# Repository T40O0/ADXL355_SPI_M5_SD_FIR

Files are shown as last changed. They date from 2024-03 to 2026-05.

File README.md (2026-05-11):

# MEMS Seismometer  


## Prerequisite
 - ADXL355 ([EVAL-ADXL355-PMDZ](https://www.analog.com/en/products/adxl355.html#product-overview))
 - [M5Stack Tough](https://docs.m5stack.com/en/core/tough)
 - [modified version](https://github.com/T40O0/M5_ADXL355/tree/M5) of [plasmapper/adxl355-arduino](https://github.com/plasmapper/adxl355-arduino)  
Hats off to PL.

## Features
 - Cost-effective: It can be made for about €100.
 - Records three acceleration components (cm/sec/sec).
 - Selectable output rate at compile time: **100 Hz** or  **500 Hz** .
 - Dual-core FreeRTOS pipeline (TaskRead on PRO_CPU, TaskSave on APP_CPU) decouples sampling from SD I/O.
 - One CSV file per minute on a TF card; daily folder layout (`/YYYYMMDD/HHMM.csv`).
 - Built-in Wi-Fi AP + FTP server for data retrieva.
 - Dust- and water-resistant (do not submerge the case in water or other liquids).
 - Made of UV-resistant plastic, so it can be used outdoors and in areas where acid gases are generated, such as volcanic regions.

## Installation
1. Connect ADXL355  
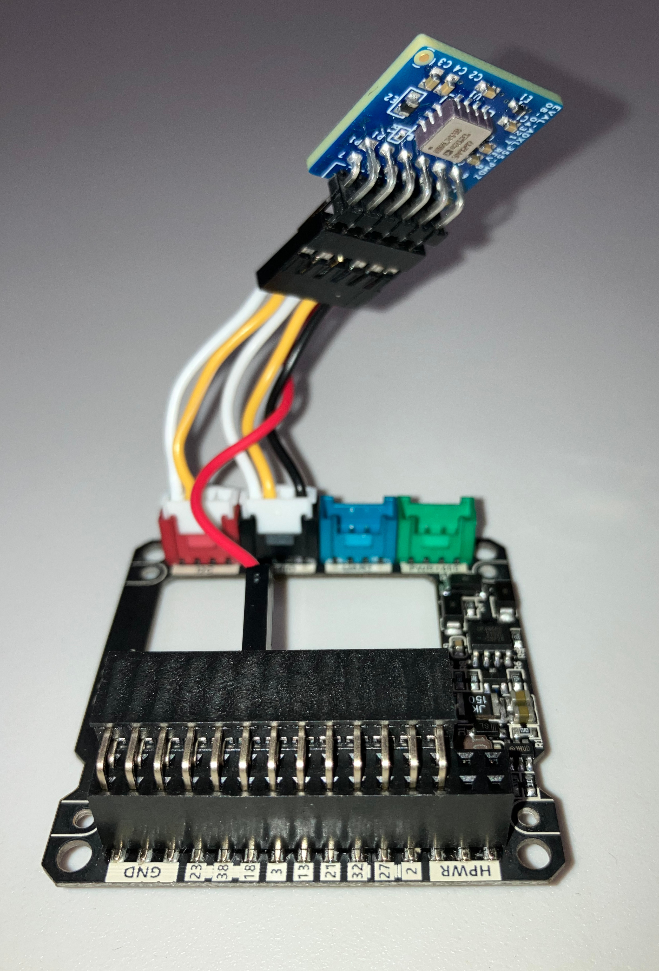
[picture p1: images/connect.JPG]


2. Set  
Mounting the ADXL355 into a [3D-printed frame](3D_model/frame.stl).  
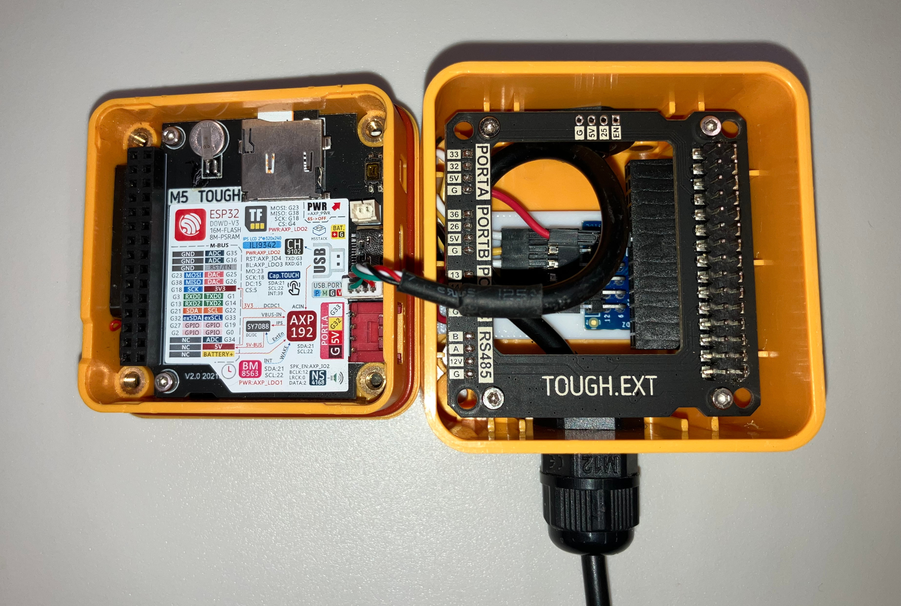
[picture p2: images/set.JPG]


3. Write  
The code can be uploaded to your board using the Arduino IDE.  
FIR coefficient files are bundled in the [`FIR/`](FIR/) subfolder of this sketch and included automatically.

## Sampling rate selection
At the top of the sketch, set the desired output rate:
```cpp
#define SAMPLE_HZ 100  // 100 or 500
```
- `100`: ADXL355 ODR=500 Hz, 201-tap FIR (`FIR/FIR500_cut50.csv`).
- `500`: ADXL355 ODR=1000 Hz, 80-tap minimum-phase FIR (`FIR/min500.cf`).

## How to start
On power-on, a startup screen with four options is shown for 30 seconds. Tap a button, or wait for the timer to elapse.

1. **Wi-Fi Setting** - SmartConfig (set or change the Wi-Fi access point), then NTP sync of the RTC.
2. **Reset RTC** - Connect to a saved Wi-Fi access point and resync the RTC via NTP.
3. **Manual Set** - Set RTC year/month/day/hour/minute/second on the touch screen (no Wi-Fi needed).
4. **Data Dump** - Start a SoftAP + FTP server. Connect a PC to the AP and pull files via Explorer.

After any of the above (or after the 30 second timeout), measurement begins at the next RTC second `00`.

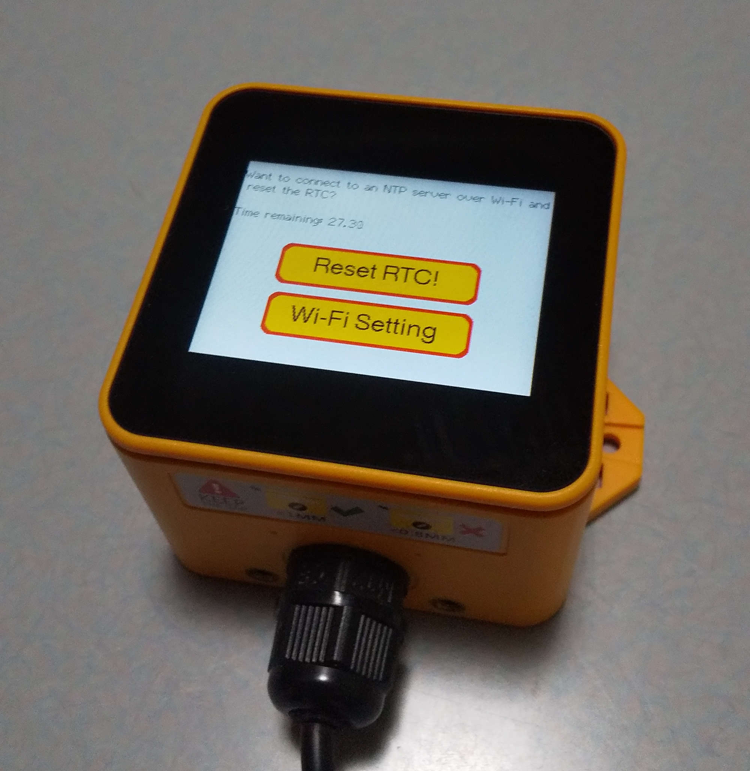
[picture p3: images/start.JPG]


## Note
 - **RTC year range**: measurements only start when the RTC year is in 2026..2099. Edit `setup()` if needed.  
   `while ((dt.date.year < 2026) || (dt.date.year > 2099)) {`
 - **NTP setup**: edit the defines near the top of the sketch to fit your environment.  
   `#define NTP_TIMEZONE  "your zone"`  
   `#define NTP_SERVER1   "your server1"`  
   `#define NTP_SERVER2   "your server2"`  
   `#define NTP_SERVER3   "your server3"`
 - **Wi-Fi setup (first time / new access point)**: choose **Wi-Fi Setting** on the startup screen, then use the *SmartConfig ESP* or *ESP Touch* app on your phone to push the SSID/password. The RTC reset proceeds automatically once the device is connected.
 - **Manual RTC**: use **Manual Set** when no Wi-Fi is available (e.g., remote field deployment). A 10-second confirmation screen is shown before measurement begins.
 - **Data Dump (FTP)**: choose **Data Dump** on the startup screen. The device acts as a SoftAP (`SSID: M5-SEISMO / PASS: m5seismo`). Connect a PC to the AP, then use a dedicated FTP client (**WinSCP**, **FileZilla**, or a web browser) at `ftp://m5:m5@192.168.4.1` to copy files. Tap the on-screen **Reset** button to return to the startup screen.
   - **Avoid Windows Explorer for the FTP transfer.** Explorer's built-in FTP shares the Internet Explorer cache and tends to keep stale copies of files across sessions, so freshly written data may not appear in the downloaded CSV even though the SD card itself is up to date. WinSCP / FileZilla / browsers fetch the current file every time and do not have this issue.
 - **FIR cutoff (100 Hz mode)**: the supplied 201-tap FIR cuts at 50 Hz for a 500 Hz input. Replace `FIR/FIR500_cut50.csv` to change the cutoff.
 - **FIR coefficients (500 Hz mode)**: this sketch ships with `FIR/min500.cf`, an 80-tap minimum-phase FIR (200 Hz passband / 250 Hz stopband at -120 dB) generated by [Telemetra-1](https://telemetra.jp/). Replace `FIR/min500.cf` with your own minimum-phase 80-tap design (declared as `double min500[80] = {...};`) to change the response.
 - **Serial debug output**: per-sample `Time(msec), x, y, z` is emitted on Serial when `#define ENABLE_SERIAL_SAMPLES 1` at the top of the sketch. Default is `0` (disabled). At 500 Hz the four `Serial.print` calls per 1 ms loop saturate the UART and add jitter to the sampling cycle, so keep it `0` for normal recording — enable only for low-rate verification.
 - **File layout**: daily folders `/YYYYMMDD/` contain per-minute files `HHMM.csv`. Each file holds 60 seconds of data, aligned to the RTC second `00`. Data captured between power-on and the first sec=0 boundary is intentionally discarded so file timing matches the file name.
 - **Timestamp resolution**: the `Time(msec)` column is stamped with `millis()` at FIFO-drain time, which has 1 ms resolution. At 500 Hz (true Δt = 2 ms) this means consecutive samples often share the same millisecond (Δt = 0) or fall on adjacent millisecond ticks (Δt = 1–6 ms), producing visible local jitter even though the **total time span** (`last − first ≈ 60000 ms`) per file remains correct. Use this metric — not the per-sample Δt — to verify recording integrity. The **per-file row count** is nominally `hz × 60` but can fluctuate by ±one batch (`hz × SDWriteTime` rows, i.e. ±7500 at 500 Hz / ±1500 at 100 Hz) at minute boundaries: TaskRead is paced by the ESP32 system tick while file rollover follows the M5 RTC (PCF8563), and the two crystals drift independently. When cumulative drift crosses one batch period, two adjacent files temporarily show one extra and one short batch; row timestamps within each file stay accurate.
 - A "[hat](3D_model/hat.stl)" is recommended for outdoor use.
   - [x] Blocks sunlight and protects the LCD.
   - [x] Falling volcanic ash is washed away by rain.
 - Do not submerge the case in water or other liquids.

## Licence
This project bundles components from multiple sources, each under its own licence:
 - **ADXL355 driver code**: based on [plasmapper/adxl355-arduino](https://github.com/plasmapper/adxl355-arduino) (PL) - see the upstream repository for its licence terms.
 - **`FIR/min500.cf` (500 Hz minimum-phase FIR)**: provided by [Telemetra-1](https://telemetra.jp/) - subject to Telemetra's own licence terms.
 - **All other original work in this repository** (sketch code, FIR/FIR500_cut50.csv, 3D models, etc.): MIT licence - see the [LICENSE file](LICENSE) for details.

When redistributing or modifying this project, please honour each component's respective licence.

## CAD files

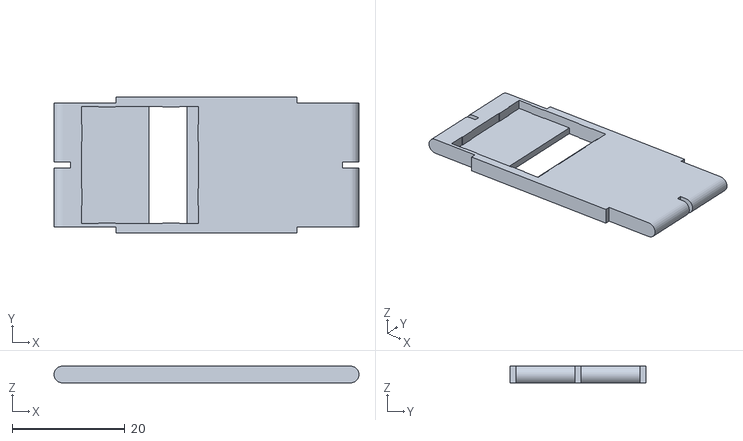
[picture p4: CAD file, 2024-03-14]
3D_model/frame.stl
54.2 x 24.1 x 3.00

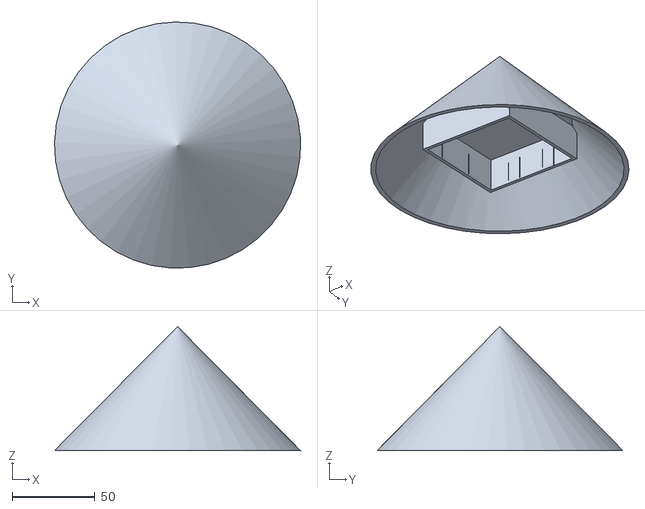
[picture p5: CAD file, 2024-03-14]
3D_model/hat.stl
148.8 x 148.8 x 75.0

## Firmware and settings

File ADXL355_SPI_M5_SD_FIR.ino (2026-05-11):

#include <SD.h>
#include <M5Unified.h>
#include <M5_ADXL355.h>

//==============================================================================
// for RTC
// M5Unified Sample
// https://github.com/m5stack/M5Unified/blob/master/examples/Basic/Rtc/Rtc.ino

#if defined ( ARDUINO )
#define NTP_TIMEZONE  "JST-9"
#define NTP_SERVER1   "ntp2.jst.mfeed.ad.jp"
#define NTP_SERVER2   "ntp1.jst.mfeed.ad.jp"
#define NTP_SERVER3   "ntp.nict.jp"

#include <WiFi.h>

#if __has_include (<esp_sntp.h>)
  #include <esp_sntp.h>
  #define SNTP_ENABLED 1
#elif __has_include (<sntp.h>)
  #include <sntp.h>
  #define SNTP_ENABLED 1
#endif

#endif

#ifndef SNTP_ENABLED
#define SNTP_ENABLED 0
#endif
//==============================================================================

// Output sampling rate (compile-time): 100 or 500 Hz.
//   100 Hz : ADXL355 ODR=500 Hz, 201-tap FIR, 50 Hz cutoff (FIR500_cut50.csv).
//   500 Hz : ADXL355 ODR=1000 Hz, 80-tap minimum-phase FIR (Telemetra min500.cf,
//            passband 200 Hz, stopband 250 Hz @ -120 dB).
#define SAMPLE_HZ 500

// Per-sample Serial output in TaskRead (debug only).
// Leave 0 for SAMPLE_HZ=500: 4 prints per 1 ms loop saturate the UART
// buffer and add jitter to the vTaskDelayUntil cycle.
#define ENABLE_SERIAL_SAMPLES 0

unsigned int hz = SAMPLE_HZ;
unsigned int dtWrite = 1000 / hz;
unsigned int SDWriteTime = 15;

// dt is shared between TaskRead and TaskSave; protect with portMUX.
auto dt = M5.Rtc.getDateTime();
portMUX_TYPE dtMux = portMUX_INITIALIZER_UNLOCKED;

char filePath[10];
char fileName[30];
int fileDate = 0;
int fileDateTime;
File f;

const String accHeader = "Time(msec),x(cm/s2),y(cm/s2),z(cm/s2)";

// FIR taps and coefficients depend on SAMPLE_HZ.
// Files live in the sketch's FIR/ subfolder.
#if SAMPLE_HZ == 100
  #define FIR_TAPS 201
  static const double FIR_COEF[FIR_TAPS] = {
    #include "FIR/FIR500_cut50.csv"
  };
#elif SAMPLE_HZ == 500
  #include "FIR/min500.cf"   // declares: double min500[80] = {...};
  #define FIR_TAPS 80
  #define FIR_COEF min500
#else
  #error "SAMPLE_HZ must be 100 or 500"
#endif

double RingBufX[FIR_TAPS] = {};
double RingBufY[FIR_TAPS] = {};
double RingBufZ[FIR_TAPS] = {};
unsigned int BufIndex = 0;

// Initial capacity for accData (~30 bytes/line * hz * SDWriteTime + margin).
const size_t ACCDATA_RESERVE = (size_t)SAMPLE_HZ * 15 * 32;

// Drop count (missed batches when the SD queue is full) .
volatile uint32_t dropCount = 0;
volatile uint32_t batchOkCount = 0;

// Latest FIR output for LCD display (vibration check).
double latestX = 0.0;
double latestY = 0.0;
double latestZ = 0.0;

//==============================================================================

// Create an instance of ADXL355
//PL::ADXL355(SCK, MISO, MOSI, SS)
PL::ADXL355 adxl355(26, 36, 32, 33);
auto range = PL::ADXL355_Range::range2g;// ADXL355 range: +/- 2 g

#if SAMPLE_HZ == 100
auto ODR = PL::ADXL355_OutputDataRate::odr500;   // sensor LPF -3 dB @ 125 Hz
unsigned int dtRead = 1000 / 500;                // 2 ms
#elif SAMPLE_HZ == 500
auto ODR = PL::ADXL355_OutputDataRate::odr1000;  // sensor LPF -3 dB @ 250 Hz
unsigned int dtRead = 1000 / 1000;               // 1 ms
#endif

auto HPF = PL::ADXL355_HpfFrequency::hpf0_0954;
auto syncTime = PL::ADXL355_Synchronization::internal;

//==============================================================================

void TaskRead( void *pvParameters );
void TaskSave( void *pvParameters );
xQueueHandle xQueue;

// FTP server state (Data Dump mode). See MiniFTP definitions below.
WiFiServer ftpCtrlSrv(21);
WiFiServer ftpDataSrv(50000);
static const uint16_t FTP_PASV_PORT = 50000;

//==============================================================================

void txtWrite(const char *string, uint16_t color) {
    M5.Lcd.fillScreen(color);
    M5.Lcd.setTextSize(1);
    M5.Lcd.setTextColor(WHITE, BLACK);
    M5.Lcd.setTextDatum(0);
    M5.Lcd.drawString(string, 0, 2, 4);
}
//==============================================================================

void createPath() {
  fileDate = dt.date.date; //Create a folder every day
  sprintf(filePath,"/%04d%02d%02d",
          dt.date.year,
          dt.date.month,
          fileDate);
  SD.mkdir(filePath);
}
//==============================================================================

// Safe TF-open helper: retry every 1 s, remount every 30 s.
static File openSDFileSafe(const char *path, const char *mode) {
  File f;
  uint32_t retry = 0;
  while (true) {
    f = SD.open(path, mode);
    if (f) {
      if (retry > 0) {
        Serial.printf("SD recovered after %u retries\n", retry);
      }
      return f;
    }
    retry++;
    Serial.printf("SD open '%s' failed, retry %u\n", path, retry);
    M5.Lcd.fillRect(0, 200, 320, 40, RED);
    M5.Lcd.setTextFont(2);
    M5.Lcd.setTextColor(WHITE, RED);
    M5.Lcd.setCursor(0, 200);
    M5.Lcd.printf("SD ERROR retry=%u", (unsigned)retry);
    M5.Lcd.setCursor(0, 220);
    M5.Lcd.print("Check SD card!");
    delay(1000);
    if (retry % 30 == 0) {
      Serial.println("Remounting SD...");
      SD.end();
      delay(500);
      SD.begin(GPIO_NUM_4, SPI, 10000000);
    }
  }
}
//==============================================================================

void createFile() {
  fileDateTime = dt.time.minutes; //Create a file every minute
  sprintf(fileName, "%s/%02d%02d.csv",
          filePath,
          dt.time.hours,
          fileDateTime);
  f = openSDFileSafe(fileName, FILE_WRITE);
  f.println(accHeader);
}
//==============================================================================

// Post-set confirmation screen, shown for 10 seconds.
static void rtcConfirmScreen() {
  static constexpr const char* const wd[7] = {"Sun","Mon","Tue","Wed","Thr","Fri","Sat"};

  M5.Lcd.fillScreen(WHITE);
  M5.Lcd.setTextColor(BLACK, WHITE);
  M5.Lcd.setTextFont(2);
  M5.Lcd.setCursor(0, 0);
  M5.Lcd.print("RTC time:");
  M5.Lcd.setCursor(0, 90);
  M5.Lcd.print("ESP32 time:");

  int prevSec = -1;
  for (int i = 100; i > 0; --i) {
    delay(100);
    auto rtcDt = M5.Rtc.getDateTime();
    auto sysT  = time(nullptr);
    auto sysTm = localtime(&sysT);

    M5.Lcd.setTextFont(4);
    M5.Lcd.setTextColor(BLACK, WHITE);
    M5.Lcd.setCursor(0, 18);
    M5.Lcd.printf("%04d/%02d/%02d (%s)",
                  rtcDt.date.year, rtcDt.date.month, rtcDt.date.date, wd[rtcDt.date.weekDay]);
    M5.Lcd.setCursor(0, 50);
    M5.Lcd.printf("%02d:%02d:%02d",
                  rtcDt.time.hours, rtcDt.time.minutes, rtcDt.time.seconds);

    M5.Lcd.setCursor(0, 108);
    M5.Lcd.printf("%04d/%02d/%02d (%s)",
                  sysTm->tm_year+1900, sysTm->tm_mon+1, sysTm->tm_mday, wd[sysTm->tm_wday]);
    M5.Lcd.setCursor(0, 140);
    M5.Lcd.printf("%02d:%02d:%02d",
                  sysTm->tm_hour, sysTm->tm_min, sysTm->tm_sec);

    int sec = i / 10;
    if (sec != prevSec) {
      M5.Lcd.setTextFont(2);
      M5.Lcd.setCursor(0, 200);
      M5.Lcd.printf("Measurement starts in %2d sec", sec);
      prevSec = sec;
    }
  }
}

//==============================================================================

// Common tail for every RTC-setting path (Set_RTC / Manual_Set / menu
// timeout): mirror the just-written M5 RTC into the system clock and
// show the 10-second confirmation screen.
static void applyRtcAndConfirm() {
  auto rtcDt = M5.Rtc.getDateTime();
  struct tm tmRtc = {};
  tmRtc.tm_year = rtcDt.date.year - 1900;
  tmRtc.tm_mon  = rtcDt.date.month - 1;
  tmRtc.tm_mday = rtcDt.date.date;
  tmRtc.tm_hour = rtcDt.time.hours;
  tmRtc.tm_min  = rtcDt.time.minutes;
  tmRtc.tm_sec  = rtcDt.time.seconds;
  time_t tt = mktime(&tmRtc);
  struct timeval tv = { tt, 0 };
  settimeofday(&tv, nullptr);
  rtcConfirmScreen();
}

//==============================================================================
void Set_RTC() {
  M5.Lcd.fillScreen(WHITE);
  M5.Lcd.setCursor(0,0);
  M5.Lcd.setTextColor(BLACK, WHITE);
  M5.Lcd.setTextFont(2);
  if (!M5.Rtc.isEnabled())
  {
    M5.Lcd.println("RTC not found.");
    delay(500);
  }
  M5.Lcd.fillScreen(WHITE);
  M5.Lcd.setCursor(0,0);
  M5.Lcd.println("RTC found.");
  delay(1000);

  M5.Lcd.setCursor(0,0);
  M5.Lcd.print("WiFi: Searching.");
  WiFi.begin();
  while (WiFi.status() != WL_CONNECTED) {
    M5.Lcd.print('.');
    delay(1000);
  }
  M5.Lcd.setCursor(0,0);
  M5.Lcd.print("Wifi: Connected.");

  configTzTime(NTP_TIMEZONE, NTP_SERVER1, NTP_SERVER2, NTP_SERVER3);

  #if SNTP_ENABLED
    while (sntp_get_sync_status() != SNTP_SYNC_STATUS_COMPLETED) {
      delay(1000);
    }
  #else
    delay(1600);
    struct tm timeInfo;
    while (!getLocalTime(&timeInfo, 1000)) {
    };
  #endif

  time_t t = time(nullptr) + 1;
  while (t > time(nullptr));
  M5.Rtc.setDateTime(localtime(&t));

  applyRtcAndConfirm();
  WiFi.disconnect(true);
}
//==============================================================================
void Set_WiFi(){
  M5.Lcd.fillScreen(WHITE);
  M5.Lcd.setTextColor(BLACK, WHITE);
  M5.Lcd.setTextFont(4);

  M5.Lcd.setCursor(0, 5);
  M5.Lcd.println("Use your phone");
  M5.Lcd.setCursor(0, 35);
  M5.Lcd.println("to select Wi-Fi.");

  WiFi.mode(WIFI_AP_STA);
  WiFi.beginSmartConfig();

  M5.Lcd.setCursor(0, 90);
  M5.Lcd.println("Waiting for");
  M5.Lcd.setCursor(0, 120);
  M5.Lcd.println("SmartConfig...");

  while (!WiFi.smartConfigDone()) {
    delay(500);
  }
  Set_RTC();
}
//==============================================================================

// Manual RTC setting UI.
void Manual_Set() {
  int year   = 2026;
  int month  = 1;
  int day    = 1;
  int hour   = 0;
  int minute = 0;
  int second = 0;

  // Button layout (320x240)
  const int xs[6]   = {   5,  80, 132, 184, 236, 288 };
  const int colW[6] = {  70,  48,  48,  48,  48,  30 };
  const int upY  = 30;
  const int dnY  = 120;
  const int btnH = 40;

  auto drawAll = [&](){
    M5.Lcd.fillScreen(WHITE);
    M5.Lcd.setTextColor(BLACK, WHITE);
    M5.Lcd.setTextFont(2);

    for (int i = 0; i < 6; i++) {
      M5.Lcd.fillRoundRect(xs[i], upY, colW[i], btnH, 5, ORANGE);
      M5.Lcd.setCursor(xs[i] + colW[i]/2 - 5, upY + btnH/2 - 8);
      M5.Lcd.setTextColor(BLACK, ORANGE);
      M5.Lcd.print("+");
    }
    for (int i = 0; i < 6; i++) {
      M5.Lcd.fillRoundRect(xs[i], dnY, colW[i], btnH, 5, ORANGE);
      M5.Lcd.setCursor(xs[i] + colW[i]/2 - 5, dnY + btnH/2 - 8);
      M5.Lcd.setTextColor(BLACK, ORANGE);
      M5.Lcd.print("-");
    }
    M5.Lcd.setTextColor(BLACK, WHITE);
    const char *hdr[6] = {"Year", "Mon", "Day", "Hour", "Min", "Sec"};
    for (int i = 0; i < 6; i++) {
      M5.Lcd.setCursor(xs[i] + 4, 5);
      M5.Lcd.print(hdr[i]);
    }
    M5.Lcd.setTextFont(4);
    char buf[8];
    int vals[6] = {year, month, day, hour, minute, second};
    for (int i = 0; i < 6; i++) {
      M5.Lcd.fillRect(xs[i], 75, colW[i], 40, WHITE);
      M5.Lcd.setCursor(xs[i] + 2, 80);
      if (i == 0) sprintf(buf, "%04d", vals[i]);
      else        sprintf(buf, "%02d", vals[i]);
      M5.Lcd.print(buf);
    }
    // SET / CANCEL
    M5.Lcd.fillRoundRect(20,  195, 130, 40, 8, GREEN);
    M5.Lcd.fillRoundRect(170, 195, 130, 40, 8, RED);
    M5.Lcd.setTextFont(4);
    M5.Lcd.setTextColor(BLACK, GREEN);
    M5.Lcd.setCursor(60, 200);
    M5.Lcd.print("SET");
    M5.Lcd.setTextColor(WHITE, RED);
    M5.Lcd.setCursor(190, 200);
    M5.Lcd.print("CANCEL");
    M5.Lcd.setTextColor(BLACK, WHITE);
  };

  auto adjust = [&](int idx, int delta){
    switch (idx) {
      case 0: year   = constrain(year + delta, 2024, 2099); break;
      case 1: month  = ((month - 1 + delta + 12) % 12) + 1; break;
      case 2: day    = ((day   - 1 + delta + 31) % 31) + 1; break;
      case 3: hour   = (hour   + delta + 24) % 24; break;
      case 4: minute = (minute + delta + 60) % 60; break;
      case 5: second = (second + delta + 60) % 60; break;
    }
  };

  // Partial redraw of one digit cell only (avoids fillScreen flicker
  // during long-press auto-repeat).
  auto drawValue = [&](int idx){
    M5.Lcd.fillRect(xs[idx], 75, colW[idx], 40, WHITE);
    M5.Lcd.setTextFont(4);
    M5.Lcd.setTextColor(BLACK, WHITE);
    M5.Lcd.setCursor(xs[idx] + 2, 80);
    char buf[8];
    int vals[6] = {year, month, day, hour, minute, second};
    if (idx == 0) sprintf(buf, "%04d", vals[idx]);
    else          sprintf(buf, "%02d", vals[idx]);
    M5.Lcd.print(buf);
  };

  drawAll();

  // Long-press auto-repeat: HOLD_DELAY -> REPEAT_SLOW -> REPEAT_FAST after ACCEL_AFTER.
  const uint32_t HOLD_DELAY_MS    = 400;
  const uint32_t REPEAT_SLOW_MS   = 150;
  const uint32_t REPEAT_FAST_MS   = 50;
  const uint32_t ACCEL_AFTER_MS   = 2000;
  int      holdBtn   = -1;          // adjust() idx (0..5), -1 = no hold
  int      holdDelta = 0;
  int      holdRow   = 0;           // upY or dnY (for in-button check)
  uint32_t holdStart = 0;
  uint32_t lastRepeat = 0;

  while (true) {
    M5.update();
    auto t = M5.Touch.getDetail();
    uint32_t now = millis();

    if (t.wasPressed()) {
      int xt = t.x;
      int yt = t.y;
      bool handled = false;

      for (int i = 0; i < 6 && !handled; i++) {
        if (xt >= xs[i] && xt <= xs[i] + colW[i] &&
            yt >= upY  && yt <= upY  + btnH) {
          adjust(i, +1);
          drawValue(i);
          holdBtn = i; holdDelta = +1; holdRow = upY;
          holdStart = lastRepeat = now;
          handled = true;
        }
      }
      for (int i = 0; i < 6 && !handled; i++) {
        if (xt >= xs[i] && xt <= xs[i] + colW[i] &&
            yt >= dnY  && yt <= dnY  + btnH) {
          adjust(i, -1);
          drawValue(i);
          holdBtn = i; holdDelta = -1; holdRow = dnY;
          holdStart = lastRepeat = now;
          handled = true;
        }
      }
      if (!handled && xt >= 20 && xt <= 150 && yt >= 195 && yt <= 235) {
        auto newdt = M5.Rtc.getDateTime();
        newdt.date.year   = year;
        newdt.date.month  = month;
        newdt.date.date   = day;
        newdt.time.hours  = hour;
        newdt.time.minutes= minute;
        newdt.time.seconds= second;
        // PCF8563 stores weekday in a separate register; compute it from the date.
        {
          static const int sakamoto_t[] = {0, 3, 2, 5, 0, 3, 5, 1, 4, 6, 2, 4};
          int yy = year - (month < 3 ? 1 : 0);
          newdt.date.weekDay = (yy + yy/4 - yy/100 + yy/400
                                + sakamoto_t[month - 1] + day) % 7;
        }
        M5.Rtc.setDateTime(&newdt);

        // Mirror the new RTC value into the system clock + show 10 s confirmation.
        applyRtcAndConfirm();
        return;
      }
      if (!handled && xt >= 170 && xt <= 300 && yt >= 195 && yt <= 235) {
        return;
      }
    }

    // While a +/- button is held, fire repeats after the initial delay, then accelerate. 
    if (holdBtn >= 0) {
      if (!t.isPressed()) {
        holdBtn = -1;
      } else {
        int xt = t.x, yt = t.y;
        bool stillIn = (xt >= xs[holdBtn] && xt <= xs[holdBtn] + colW[holdBtn] &&
                        yt >= holdRow    && yt <= holdRow    + btnH);
        if (!stillIn) {
          holdBtn = -1;
        } else {
          uint32_t held = now - holdStart;
          if (held >= HOLD_DELAY_MS) {
            uint32_t interval = (held >= ACCEL_AFTER_MS) ? REPEAT_FAST_MS
                                                         : REPEAT_SLOW_MS;
            if (now - lastRepeat >= interval) {
              adjust(holdBtn, holdDelta); drawValue(holdBtn);
              lastRepeat = now;
            }
          }
        }
      }
    }

    delay(20);
  }
}

//==============================================================================

// MiniFTP state (control connection, current cwd, auth flag, login arg).
static WiFiClient ftpCli;
static String    ftpCwd     = "/";
static bool      ftpAuthed  = false;
static String    ftpUserArg;
static IPAddress ftpLocalIP;

static const char *FTP_USER = "m5";
static const char *FTP_PASS = "m5";

// Resolve an FTP path argument relative to ftpCwd.
static String ftpResolve(const String &arg) {
  if (arg.length() == 0) return ftpCwd;
  if (arg.startsWith("/")) return arg;
  if (ftpCwd == "/") return "/" + arg;
  return ftpCwd + "/" + arg;
}

// Send a code+message line on the FTP control connection.
static void ftpReply(int code, const char *msg) {
  ftpCli.printf("%d %s\r\n", code, msg);
}

// Wait for a passive-mode data client to connect (timeout in ms).
static WiFiClient ftpAcceptData(uint32_t timeoutMs = 5000) {
  uint32_t t0 = millis();
  while (millis() - t0 < timeoutMs) {
    WiFiClient c = ftpDataSrv.accept();
    if (c) return c;
    delay(10);
  }
  return WiFiClient();
}
//==============================================================================
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
void loop() {
  delay(1000);
}
//==============================================================================

void TaskRead(void *pvParameters) {
  auto accelerations = adxl355.getAccelerations();
  unsigned long sTime = 1;
  unsigned int i = 1;
  unsigned int j = 1;
  unsigned int k = 0;
  unsigned int l = 0;
  double AccX = 0., AccY = 0., AccZ = 0.;
  double AccFirX = 0., AccFirY = 0., AccFirZ = 0.;
  String accData;
  accData.reserve(ACCDATA_RESERVE);

  auto localDt = M5.Rtc.getDateTime();
  txtWrite("waiting start...", BLACK);
  while (localDt.time.seconds != 0) {
    delay(1);
    localDt = M5.Rtc.getDateTime();
  }
  portENTER_CRITICAL(&dtMux);
  dt = localDt;
  portEXIT_CRITICAL(&dtMux);

  TickType_t xLastWakeTimeSend = xTaskGetTickCount();

  for (;;) {
    while (j <= dtWrite / dtRead) {
      vTaskDelayUntil(&xLastWakeTimeSend, dtRead / portTICK_PERIOD_MS);
      sTime = millis();
      accelerations = adxl355.getAccelerations();
      AccX = accelerations.x;
      AccY = accelerations.y;
      AccZ = accelerations.z;
      if (BufIndex >= FIR_TAPS) BufIndex = 0;
      RingBufX[BufIndex] = AccX;
      RingBufY[BufIndex] = AccY;
      RingBufZ[BufIndex] = AccZ;
      BufIndex++;
      j++;
    }
    j = 1;

    // FIR Filter & decimation
    l = BufIndex - 1;
    for (k = 0; k < (unsigned int)FIR_TAPS; k++) {
      if (l < k) l = FIR_TAPS - 1 + k;
      AccFirX += FIR_COEF[k] * RingBufX[l - k];
      AccFirY += FIR_COEF[k] * RingBufY[l - k];
      AccFirZ += FIR_COEF[k] * RingBufZ[l - k];
    }

    accData += '\n';
    accData += sTime;
    accData += ',';
    accData += AccFirX;
    accData += ',';
    accData += AccFirY;
    accData += ',';
    accData += AccFirZ;

#if ENABLE_SERIAL_SAMPLES
    Serial.print(sTime);
    Serial.print(", ");
    Serial.print(AccFirX);
    Serial.print(", ");
    Serial.print(AccFirY);
    Serial.print(", ");
    Serial.println(AccFirZ);
#endif

    latestX = AccFirX;
    latestY = AccFirY;
    latestZ = AccFirZ;

    AccFirX = 0;
    AccFirY = 0;
    AccFirZ = 0;

    if (i >= hz * SDWriteTime) {
      String *snapshot = new String(accData);
      if (xQueueSendToBack(xQueue, &snapshot, 0) != pdTRUE) {
        delete snapshot;
        dropCount++;
      }
      accData = "";
      i = 1;
    }
    else {
      i++;
    }
  }
}
//==============================================================================

void TaskSave(void *pvParameters) {
  String *recData = nullptr;
  bool firstBatch = true;

  delay(5);

  for (;;) {
    // Check xQueueReceive return; skip write on timeout.
    if (xQueueReceive(xQueue, &recData, SDWriteTime * 1000 / portTICK_PERIOD_MS) != pdTRUE) {
      auto localDt = M5.Rtc.getDateTime();
      portENTER_CRITICAL(&dtMux);
      dt = localDt;      portEXIT_CRITICAL(&dtMux);
      continue;
    }

    // First batch: create file with post sec=0 RTC so name matches start minute.
    if (firstBatch) {
      auto firstDt = M5.Rtc.getDateTime();
      portENTER_CRITICAL(&dtMux);
      dt = firstDt;
      portEXIT_CRITICAL(&dtMux);
      createPath();
      createFile();
      firstBatch = false;
    }

    *recData += '\n';
    f.print(recData->substring(1));
    f.close();
    batchOkCount++;

    auto localDt = M5.Rtc.getDateTime();
    portENTER_CRITICAL(&dtMux);
    dt = localDt;      portEXIT_CRITICAL(&dtMux);

    // Power save: backlight ON only while showing the per-batch panel
    // (~3 s out of every SDWriteTime), OFF otherwise.
    M5.Lcd.setBrightness(100);

    M5.Lcd.fillScreen(BLACK);
    M5.Lcd.setTextColor(WHITE, BLACK);
    M5.Lcd.setTextFont(4);
    M5.Lcd.setCursor(0, 0);
    M5.Lcd.printf("%04d/%02d/%02d %02d:%02d:%02d",
                  localDt.date.year, localDt.date.month, localDt.date.date,
                  localDt.time.hours, localDt.time.minutes, localDt.time.seconds);

    M5.Lcd.setTextFont(2);
    M5.Lcd.setCursor(0, 40);
    M5.Lcd.printf("X: %8.2f cm/s2", latestX);
    M5.Lcd.setCursor(0, 60);
    M5.Lcd.printf("Y: %8.2f cm/s2", latestY);
    M5.Lcd.setCursor(0, 80);
    M5.Lcd.printf("Z: %8.2f cm/s2", latestZ);

    M5.Lcd.setCursor(0, 110);
    M5.Lcd.printf("OK  : %lu", (unsigned long)batchOkCount);
    // DROP = number of dropped batches (queue full from slow SD writes).
    M5.Lcd.setCursor(0, 130);
    M5.Lcd.setTextColor(dropCount ? RED : WHITE, BLACK);
    M5.Lcd.printf("DROP: %lu", (unsigned long)dropCount);
    M5.Lcd.setTextColor(WHITE, BLACK);

    delay(SDWriteTime * 1000 / 5);
    M5.Lcd.fillScreen(BLACK);
    M5.Lcd.setBrightness(0); //End

    delete recData;
    recData = nullptr;

    if (localDt.time.minutes != fileDateTime) {
      if (localDt.date.date != fileDate) {
        portENTER_CRITICAL(&dtMux);
        dt = localDt;
        portEXIT_CRITICAL(&dtMux);
        createPath();
      }
      portENTER_CRITICAL(&dtMux);
      dt = localDt;
      portEXIT_CRITICAL(&dtMux);
      createFile();
    }
    else {
      // Use openSDFileSafe here.
      f = openSDFileSafe(fileName, FILE_APPEND);
    }
  }
}

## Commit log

2024-03-15 Display error if TF Card is not inserted.
    [ADXL355_SPI_M5_SD_FIR.ino]
2024-04-10 Added the ability to update Wi-Fi information
    Update Wi-Fi information in ESP32 from EspTouch using SmartConfig.
2026-04-06 Keep I2C connection with the RTC
2026-05-07 Fix concurrency bugs and add Manual Set / Data Dump UI
    Bug fixes:
    - B1: open initial file in setup() before tasks start (no first-batch loss)
    - B2: send heap-allocated String* via queue (deep copy, no buffer race)
    - B3: check xQueueReceive return value (skip write on timeout)
    - B4: count xQueueSendToBack drops, show warning on LCD
    - B5: protect global dt with portMUX critical sections
    - B7: countdown loop now matches real time (added delay 100ms)
    - B8: relax RTC year range upper bound (2031 -> 2099)
    - B12: portTICK_RATE_MS -> portTICK_PERIOD_MS
    - B14: typo fixes (Strat->Start, waite->waiting, begginig->beginning)
    - C5: partial LCD updates instead of fillScreen every batch
    - C6: removed temp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
    [ADXL355_SPI_M5_SD_FIR.ino]
2026-05-07 Switch FTP library: SimpleFTPServer -> ESP-FTP-Server-Lib
    Avoid the DEFAULT_STORAGE_TYPE_ESP32 macro override issue in
    SimpleFTPServer/FtpServerKey.h that forced FFat instead of SD.
    Changes:
    - Drop #define DEFAULT_STORAGE_TYPE_ESP32 STORAGE_SD (no longer needed)
    - Replace #include <SimpleFTPServer.h> with
    #include <ESP-FTP-Server-Lib.h>
    #include <FTPFilesystem.h>
    - Rename FtpServer -> FTPServer (peterus library naming)
    - Update Data_Dump_FTP() to new API:
    ftpSrv.addUser("m5", "m5");
    ftpSrv.addFilesystem("SD", &SD);
    ftpSrv.begin();
    ftpSrv.handle(); // was handleFTP() in old lib
    Requires Arduino library "ESP-FTP-Server-Lib" (peterus) to be installed.
    [ADXL355_SPI_M5_SD_FIR.ino]
2026-05-07 Replace FTP with built-in WebServer.h + streaming ZIP download
    External FTP libraries had ongoing issues (macro override, manual install,
    auto-update breakage). Switch to ESP32 standard WebServer.h with custom
    HTTP file server. No external library dependencies.
    Features:
    - HTTP file server on http://192.168.4.1 (SoftAP "M5-SEISMO")
    - Browser-based UI with file/folder listing
    - Individual file download (Content-Disposition attachment)
    - Folder ZIP download: /zip?p=/<folder>
    - Whole-SD ZIP download: /zipall (recursive)
    - Streaming ZIP creation (uncompressed store, ZIP-32, max 4GB)
    - Inline CRC32 implementation, no external deps
    Code structure:
    - listDir(): collect SD entries
    - streamZip(): e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
    [ADXL355_SPI_M5_SD_FIR.ino]
2026-05-07 FIR UI/UX fixes after first build
    User feedback after successful build:
    1. Wait countdown 10s -> 30s (300 iterations x 100ms with sec display)
    2. Manual_Set: widen Year column (4 digits) so it doesn't overlap Month
    - xs[6] / colW[6] arrays for per-column width
    - Touch detection uses colW[i]
    3. Manual_Set: add 10s confirmation screen after SET, like Set_RTC
    4. Data_Dump_HTTP: initialize SD.begin() inside the function since it
    runs from setup() before main SD.begin() (was returning empty list)
    5. TaskSave LCD: replace continuous display with 3s-on/12s-off cycle
    (burn-in mitigation). Show time, X/Y/Z (latest FIR output) and
    OK/DROP counters. DROP shown red when >0.
    - latestX/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
    [ADXL355_SPI_M5_SD_FIR.ino]
2026-05-07 FIR: second round of UI fixes after build feedback
    User feedback after testing the previous build:
    1. Manual_Set: layout still cramped, fields wrapping to 2 lines
    - Year column 80->70, others 44->48 (uniform), Sec 30 (corner)
    - xs[6]={5,80,132,184,236,288}, colW[6]={70,48,48,48,48,30}
    - Default value: hardcoded 2026/01/01 00:00:00 (was reading RTC)
    - Down button moved up: dnY 140->120 (gap to SET button: 15->35px)
    to prevent accidentally hitting SET when pressing Down(-)
    - Header text moved to y=5 (was y=20, would overlap up buttons)
    2. NTP fail handling: revert to original blocking behavior
    - Removed tryNtpSync() helper
    - Set_RTC uses original WiFi.begin() + sntp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
    [ADXL355_SPI_M5_SD_FIR.ino]
2026-05-07 FIR: third round of UI fixes (text overflow, ZIP DL, flicker)
    User feedback after second build test:
    1. Set_WiFi text overflow: explicit setTextFont(4) and split text into
    short lines (max ~22 chars at font 4 on 320px wide screen).
    "Use your phone to select Wi-Fi." (31 chars) -> two lines.
    2. ZIP folder download stuck at 0 bytes/sec: completely rewrote
    streamZip() to use Content-Length + ZIP data descriptor format:
    - Pass 1: collect file sizes via f.size() (no read)
    - Compute exact total ZIP size (local hdr + name + data + 16-byte
    data descriptor per file, plus CD entries plus EOCD)
    - setContentLength(totalSize) -> standard HTTP, NOT chunked
    - Pass 2: write header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
    [ADXL355_SPI_M5_SD_FIR.ino]
2026-05-07 FIR: ZIP timeout fix, Reset button, B11 SD retry
    1. Reset button on Data Dump screen
    - Touch button at bottom of LCD (200x40, RED/ORANGE rounded rect)
    - On tap: ESP.restart() returns to startup menu
    - Previous "Reset M5 to exit." text replaced with actual button
    2. ZIP download still 0 bytes/sec - real root cause:
    - streamZip() Pass 1 was opening every file via SD.open(path) just
    to call f.size(). For 1440 files that's ~43 seconds of SD I/O
    before any data is sent -> browser timeout -> 0 bytes/sec.
    - Fix: collect file sizes during initial dir.openNextFile() iteration
    where each entry's size() is already accessible without re-open.
    - listDir() gains optional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
    [ADXL355_SPI_M5_SD_FIR.ino]
2026-05-07 FIR: button labels, ZIP perf, browser compat fixes
    1. Startup menu button labels:
    - Remove "!" from "Reset RTC!" -> "Reset RTC"
    - Replace per-label centering with fixed left margin (btnX + 25)
    so all labels (especially "Wi-Fi Setting") share the same X start.
    2. ZIP download performance and browser compat:
    - client.setNoDelay(true): disable Nagle, more responsive small writes
    (helps strict browsers like Vivaldi see immediate progress).
    - Streaming buffer 1KB -> 4KB: fewer SD reads, better SD/WiFi overlap.
    - Explicit client.stop() after EOCD: ensures clean EOF detection.
    - WebServer.on() now registers without HTTP_GET method filter so
    HEAD requests (some brow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
    [ADXL355_SPI_M5_SD_FIR.ino]
2026-05-07 FIR: SAMPLE_HZ 100/500 selection + comments to English
    Sampling rate selection (compile-time):
    #define SAMPLE_HZ 100 // 100 or 500
    - 100 Hz: ADXL355 ODR=500, 201-tap FIR cutoff 50 Hz (FIR500_cut50.csv).
    - 500 Hz: ADXL355 ODR=1000, 80-tap minimum-phase FIR (Telemetra
    min500.cf). Passband 200 Hz, stopband 250 Hz @ -120 dB.
    Two #if/#elif blocks select ODR/dtRead/FIR_TAPS/FIR_COEF accordingly.
    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
2026-05-07 FIR: bundle coefficient files in sketch FIR/ subfolder
    Rename into_library/ -> FIR/ and update #include paths to use
    relative paths ("FIR/FIR500_cut50.csv", "FIR/min500.cf"). Arduino IDE
    adds the sketch directory to the include search path, so the files
    are now found without requiring a separate copy in the user's
    Arduino libraries folder.
    The library-folder copy of FIR500_cut50.csv that previous versions
    required can be deleted; it is no longer referenced.
    README updated to drop the "copy to library folder" instruction.
    [FIR500_cut50.csv]
2026-05-07 FIR: ZIP DL via chunked + sendContent (Vivaldi compat)
    Vivaldi was starting the ZIP download but stalling at 0 KB/sec while
    single-file streamFile() worked fine in both browsers. Switching the
    ZIP path from raw client.write() with Content-Length to chunked
    transfer + httpSrv.sendContent() aligns ZIP delivery with the same
    pipeline ESP32 WebServer uses for streamFile().
    - setContentLength(CONTENT_LENGTH_UNKNOWN) instead of computed total.
    - All writes go through httpSrv.sendContent(...). The trailing
    sendContent("") emits the empty terminating chunk so the browser
    can detect end-of-stream.
    - yield() inside the file read loop so the LWIP/WiFi tasks can drain
    the TCP send buffer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
    [ADXL355_SPI_M5_SD_FIR.ino]
2026-05-07 FIR: explicit client.stop() after final ZIP chunk
    Vivaldi was receiving all ZIP bytes (progress bar 100%, 3.63 / 3.63
    MB) but kept the download in a waiting state because the TCP
    connection was not closed promptly. ESP32 WebServer eventually closes
    on its own but some browsers expect EOF (FIN) immediately after the
    final chunk.
    Add httpSrv.client().flush() + 50 ms drain + httpSrv.client().stop()
    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
2026-05-07 FIR: ZIP DL via Content-Length + raw client.write (plan A)
    Switch the ZIP path to the same scheme as streamFile() which Vivaldi
    handles cleanly:
    - setContentLength(totalSize) (exact size, computed from listDir sizes).
    - Raw client.write() for everything (no httpSrv.sendContent).
    - Browser knows the total upfront -> accurate progress bar, completes
    as soon as the last byte arrives (no "0 bytes/sec waiting" state).
    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
2026-05-07 FIR: ZIP DL coalesce per-file writes (1 write per file)
    Root cause of the Edge slowness and Vivaldi quirk: the previous code
    issued ~16 client.write() calls per file (header + name + 13x4KB data
    chunks + data descriptor). Each client.write() incurs lwip + WiFi
    handoff overhead, and 10 files thus produced ~160 writes -> ~11 s for
    500 KB.
    Coalesce each file's full ZIP entry into a single PSRAM buffer
    (hdr + name + data + dd) and emit it with one client.write(). The
    data is read directly into the buffer and CRC32-ed in place. For
    10 files this drops the write count to ~12 (10 file entries + CD +
    EOCD).
    Other refinements:
    - Loop on partial writes (size_t written; while (written < bufSize))
    t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
    [ADXL355_SPI_M5_SD_FIR.ino]
2026-05-07 FIR: ZIP traditional format (no data descriptor) for browser compat
    Vivaldi was correctly receiving 100% of the ZIP bytes (Content-Length
    matched perfectly) but kept the download in a waiting state. Vivaldi
    appears to validate ZIP entries on the fly; with the data descriptor
    format (flag bit 3, CRC trailing the data) the download manager waits
    for an end-of-stream signal that the streamFile path does not emit.
    Switch to the traditional ZIP format:
    - Local file header carries the actual CRC and uncompressed/compressed
    sizes inline; flag = 0 (no data descriptor follows).
    - No 16-byte data descriptor after the data.
    - Central directory entries also flag = 0.
    Each entry remains self-containe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
    [ADXL355_SPI_M5_SD_FIR.ino]
2026-05-07 FIR: add section separators between functions
    Insert //==============================================================================
    between major function definitions for visual separation:
    - crc32Init / crc32Update
    - listDir / handleRoot / handleFolder / handleDownload / streamZip /
    handleZipFolder / handleZipAll / Data_Dump_HTTP
2026-05-07 FIR: ZIP DL mirror streamFile() lifecycle exactly
    streamFile() works in Vivaldi; my streamZip did not, even after
    matching Content-Length / traditional ZIP. The remaining difference
    was lifecycle handling. Mirror the streamFile() flow exactly:
    - Drop the explicit "Connection: close" response header.
    - Drop client.flush() and client.stop() calls.
    - Use httpSrv.sendContent() instead of grabbing client = httpSrv.client()
    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
2026-05-07 FIR: replace WebServer/ZIP with self-contained minimal FTP server
    The WebServer-based bulk ZIP download never worked reliably in Vivaldi
    and was slow in Edge. Switch the Data Dump mode to a minimal FTP
    server implemented entirely inline (no external library, no library
    edits, no manual GitHub install). Windows Explorer can browse the
    M5's SD via ftp://m5:m5@192.168.4.1.
    Removed:
    - WebServer httpSrv (and the include)
    - handleRoot / handleFolder / handleDownload (HTML browsing)
    - streamZip / handleZipFolder / handleZipAll (custom ZIP streaming)
    - crc32Init / crc32Update / crc32Table (only used by ZIP)
    - listDir helper (no longer needed)
    - Data_Dump_HTTP function
    - <vector> include
    Added (inl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
    [ADXL355_SPI_M5_SD_FIR.ino]
2026-05-07 FIR: revert B1 file pre-create; defer file creation to first batch
    - setup() no longer pre-creates the first CSV; doing so labeled the
    initial file with the setup-time minute, while data actually begins
    one alignment boundary later (sec=0). Result was first file 15 s,
    second 45 s, third onward 60 s.
    - TaskSave now creates path/file on the first received batch using the
    post-alignment RTC, so file names always match the actual data start.
    - Restores the original design: data captured between power-on and the
    first sec=0 boundary is intentionally discarded.
    - README: rewritten Features / How to start / Note for the four-button
    startup menu and built-in FTP. Document Telemetra-1 500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
    [ADXL355_SPI_M5_SD_FIR.ino]
2026-05-08 FIR: fix Manual_Set weekday with Sakamoto's algorithm
    PCF8563-class RTCs store weekday in a separate register that is not
    derived from the date. The previous Manual_Set code wrote the new
    year/month/day to the RTC but left the weekday field unchanged, so
    rtcConfirmScreen sometimes displayed a weekday on the RTC line that
    disagreed with the system clock (computed via localtime).
    Compute the correct day-of-week (0=Sun..6=Sat) from year/month/day
    with Sakamoto's method (TZ-independent, no mktime side effects)
    before writing to the RTC.
    [ADXL355_SPI_M5_SD_FIR.ino]
2026-05-08 FIR: Manual_Set long-press auto-repeat + comment cleanup
    - Manual_Set +/- buttons now auto-repeat after 400 ms of holding:
    ~7 Hz (REPEAT_SLOW) initially, accelerating to ~20 Hz (REPEAT_FAST)
    after 2 s. Repeat stops when the finger is lifted or dragged off
    the original button.
    - Comment cleanup: drop obvious one-line comments (// Initialize M5
    / // Initialize ADXL355 / // Start SD / // define two tasks /
    // queue / // Make sure the data server... / // UNIX-style ls -l...
    / // Different versions of the framework... etc.), shorten multi-
    line block comments around applyRtcAndConfirm, openSDFileSafe, the
    Sakamoto weekday computation, the dispatched flag rationale, etc.
    [ADXL355_SPI_M5_SD_FIR.ino]
2026-05-08 FIR: power save + Manual_Set flicker fix
    Manual_Set: introduce drawValue(idx) lambda that repaints just one
    digit cell. Single taps and long-press auto-repeats now use it instead
    of the full-screen drawAll(), so the +/- buttons no longer flash the
    whole panel each repeat tick.
    TaskSave: bring the LCD backlight up only while the per-batch status
    panel is visible (~3 s out of every SDWriteTime). After the visible
    window the screen is wiped to BLACK *and* setBrightness(0) is called,
    which on M5Stack Tough kills the backlight LED itself. Net effect:
    backlight on ~20 % of the time, which is the dominant power draw of
    the device, so the saving is worth roughly an extra hour per battery
    charge for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
    [ADXL355_SPI_M5_SD_FIR.ino]
2026-05-09 FIR: README note on millis() 1 ms timestamp resolution
2026-05-11 FIR: ENABLE_SERIAL_SAMPLES toggle + localize FIR accumulators + README drift note
    [ADXL355_SPI_M5_SD_FIR.ino]
